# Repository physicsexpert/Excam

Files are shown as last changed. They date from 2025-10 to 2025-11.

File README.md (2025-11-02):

# Excam是一款基于openmv的多功能小相机
## Excam主控采用stm32h7343（stm32h750），搭载1.8寸180°翻转屏，电池，补光灯，RGB灯，按键，SD卡，支持OV5640、OV2640摄像头，支持引脚拓展，兼容openmv固件（引出SWD接口），可以实现色块识别、人脸识别、边缘检测、模板匹配、特征点检测等功能，可以跑一些简单的神经网络模型。

## B站视频链接：
## 开源资料链接：https://pan.quark.cn/s/5be252dfcba2?pwd=E3c6
# 产品渲染图
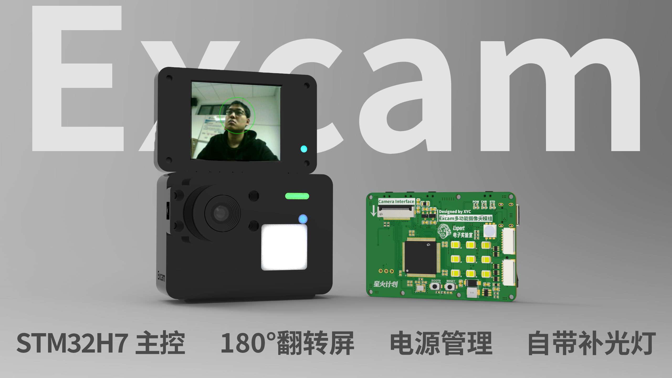
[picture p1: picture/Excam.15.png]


# 产品实物图

## 外观
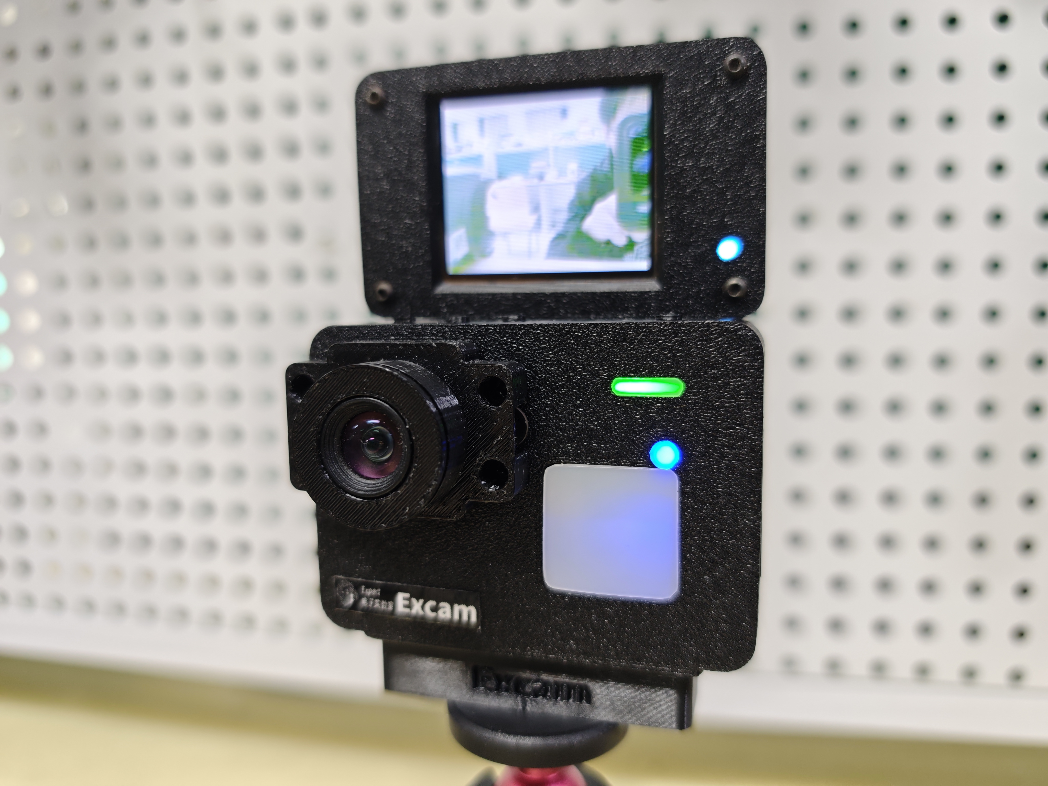
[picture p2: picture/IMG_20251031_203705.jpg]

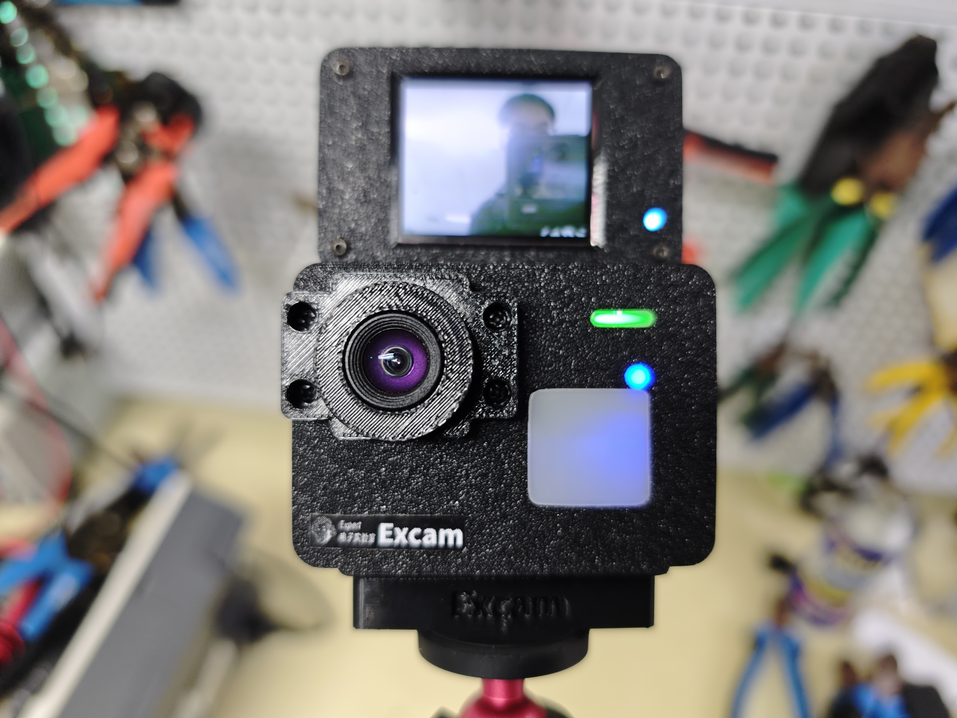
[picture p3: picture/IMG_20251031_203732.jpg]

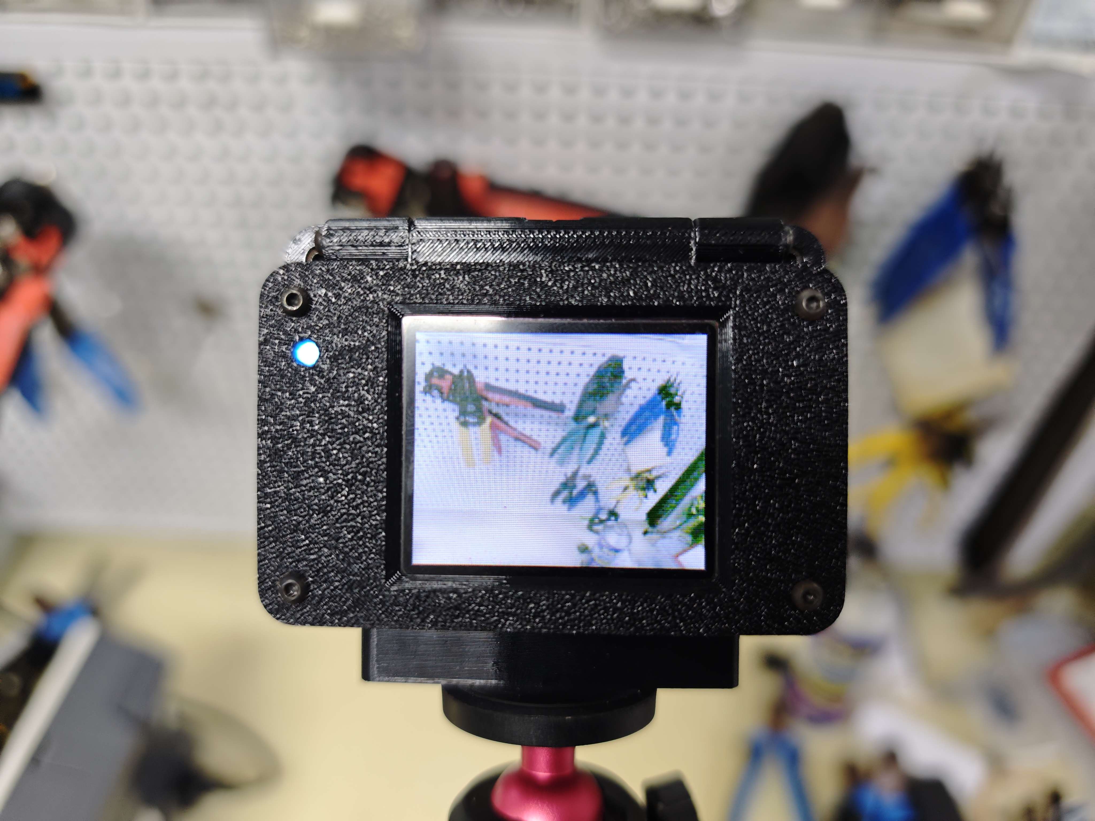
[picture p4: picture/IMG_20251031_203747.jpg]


## 部分功能展示（色块识别、人脸识别、边缘检测、目标检测）
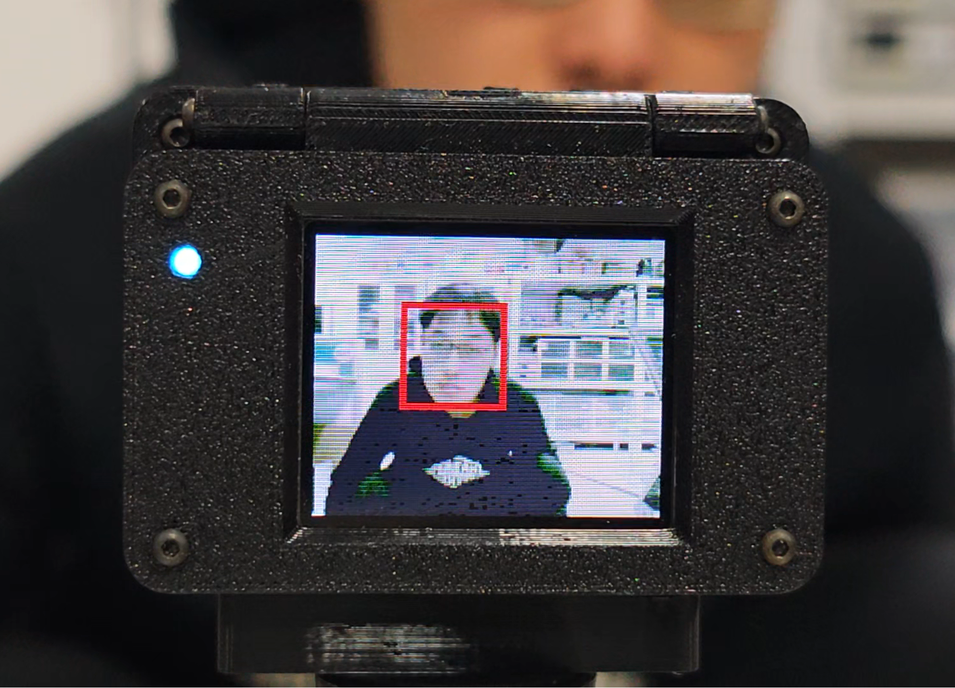
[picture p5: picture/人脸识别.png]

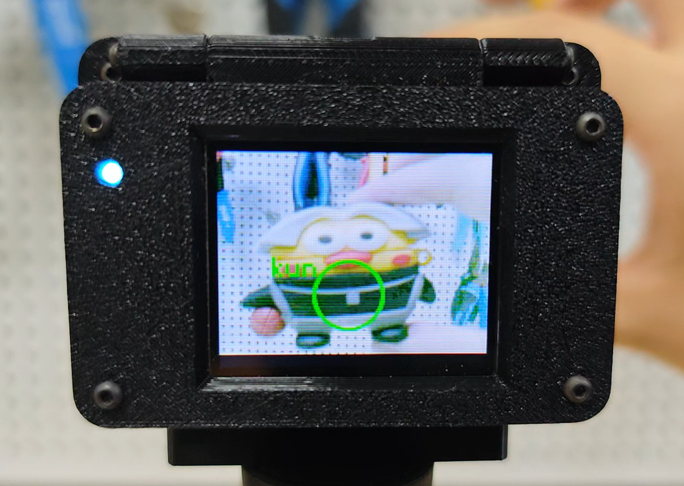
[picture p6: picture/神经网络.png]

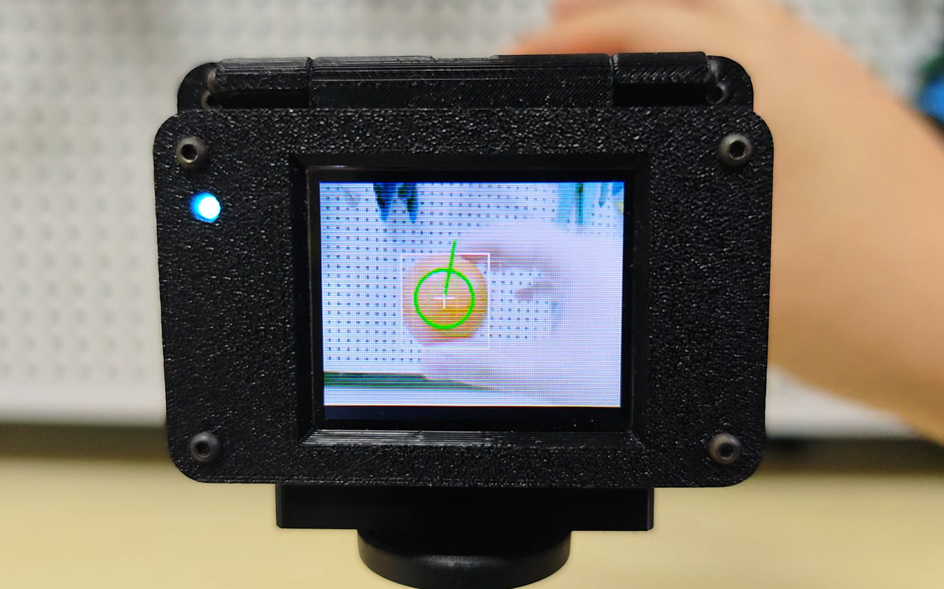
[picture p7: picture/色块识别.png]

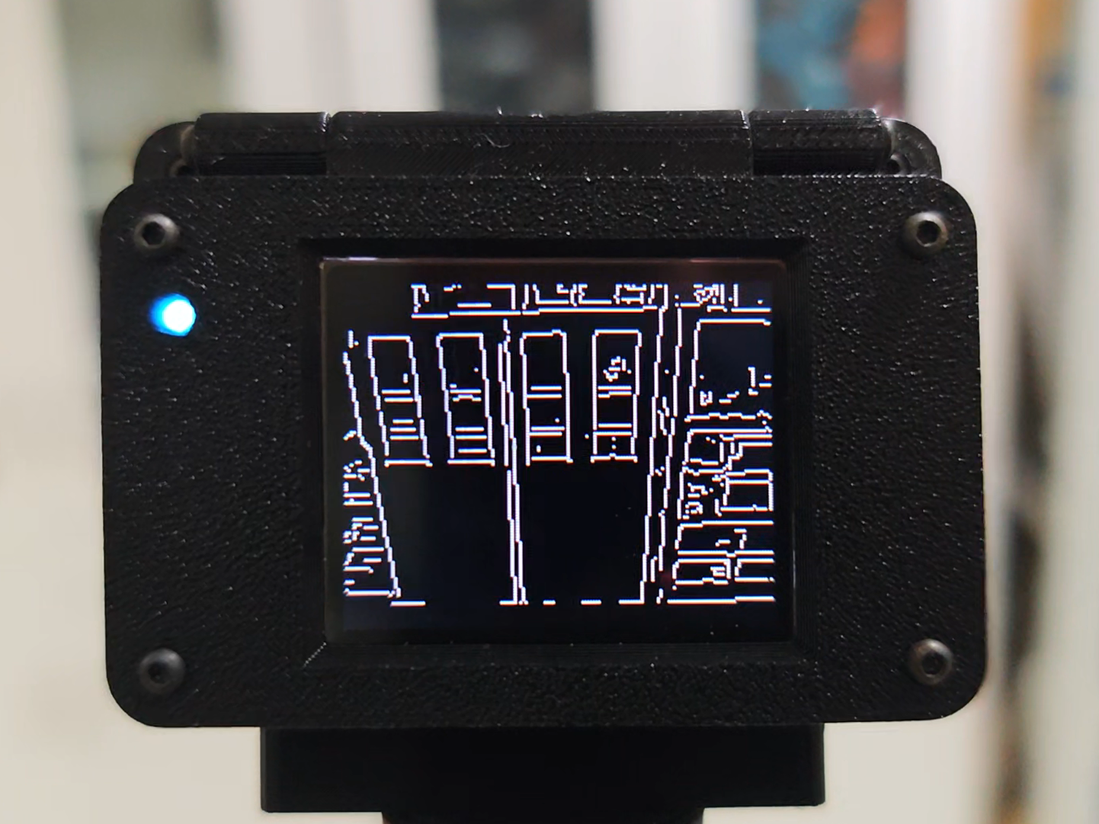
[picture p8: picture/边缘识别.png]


## 所有部件一览
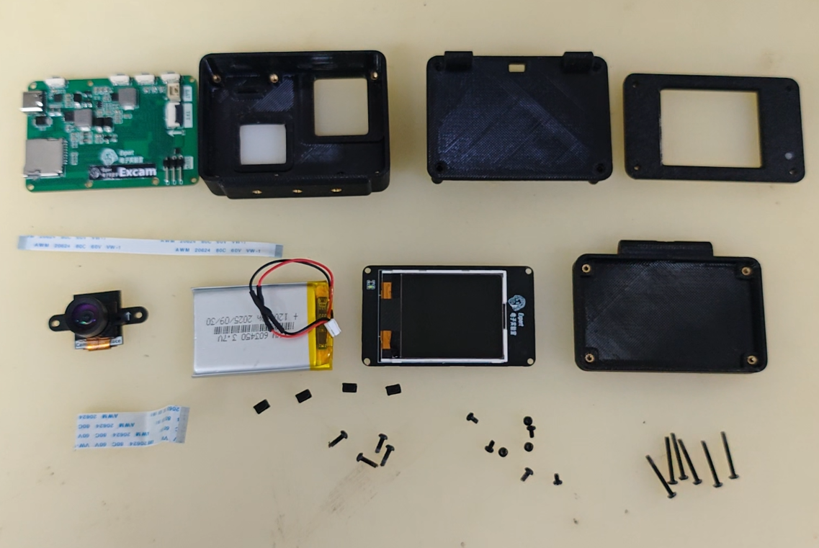
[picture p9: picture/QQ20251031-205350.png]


## 内部结构
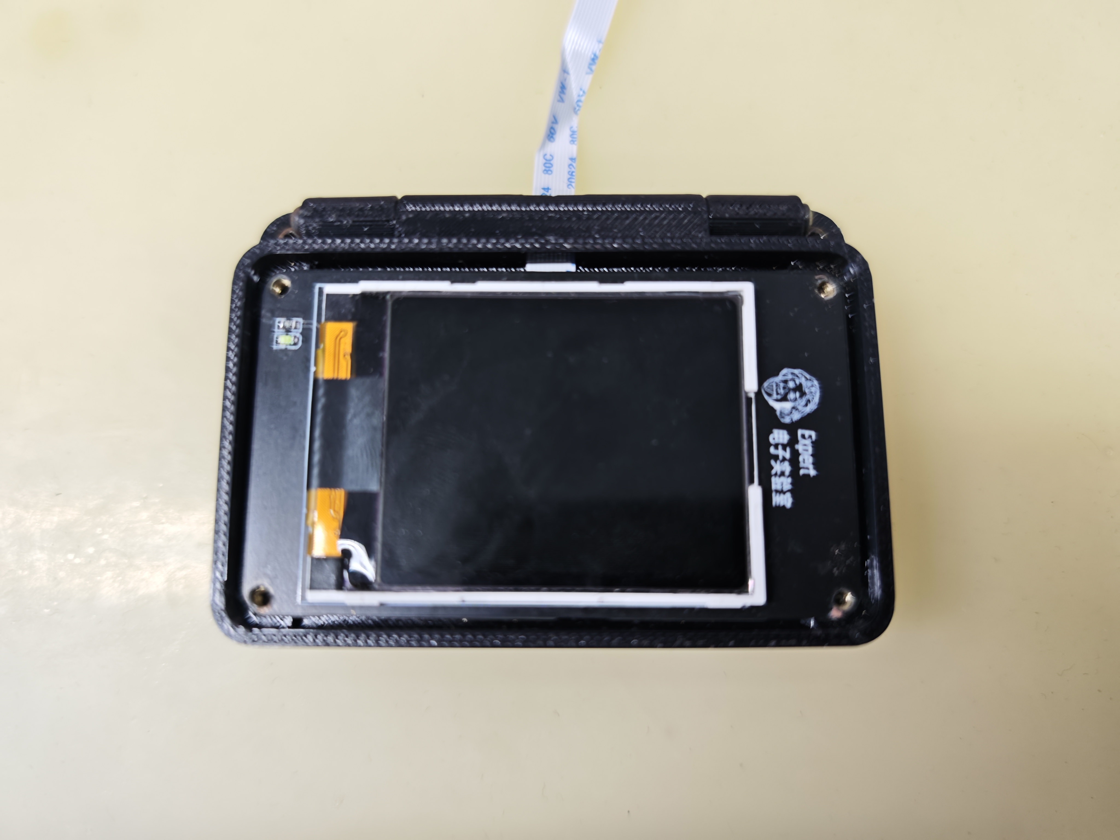
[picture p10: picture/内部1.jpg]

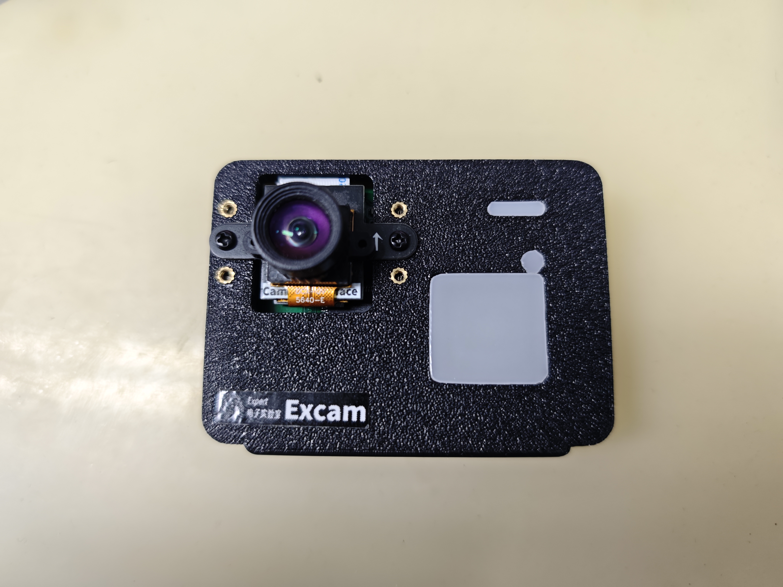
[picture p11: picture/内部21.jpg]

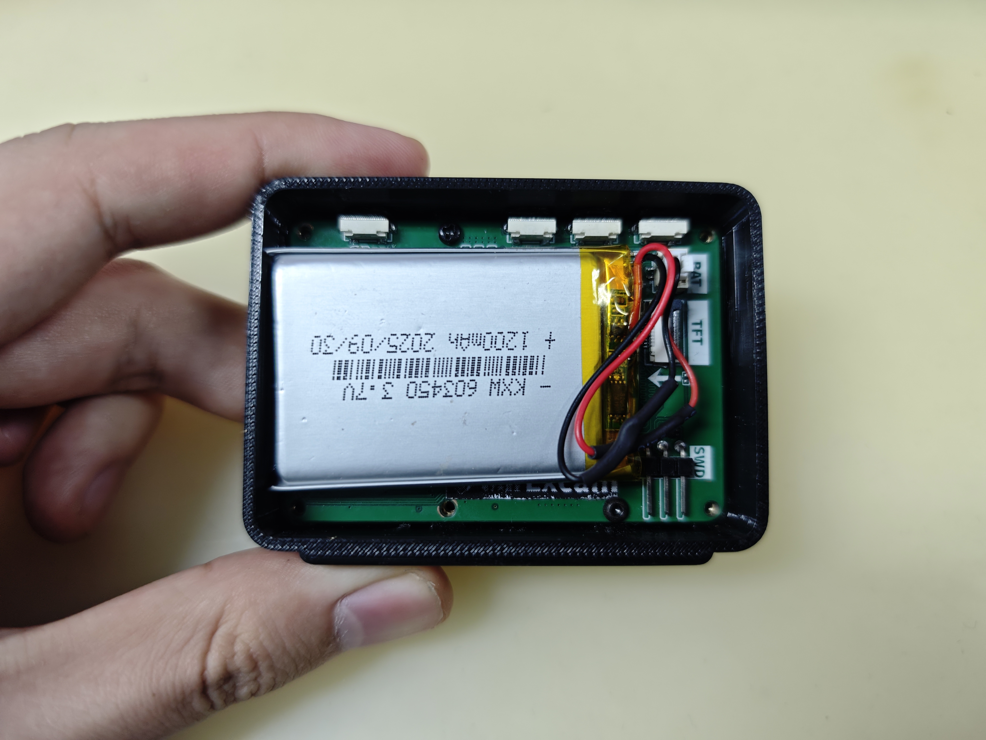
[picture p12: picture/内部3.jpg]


# 硬件说明
## 排针引脚功能（通过侧面SH1.0的接口引出，可以外接杜邦线或者排线）：
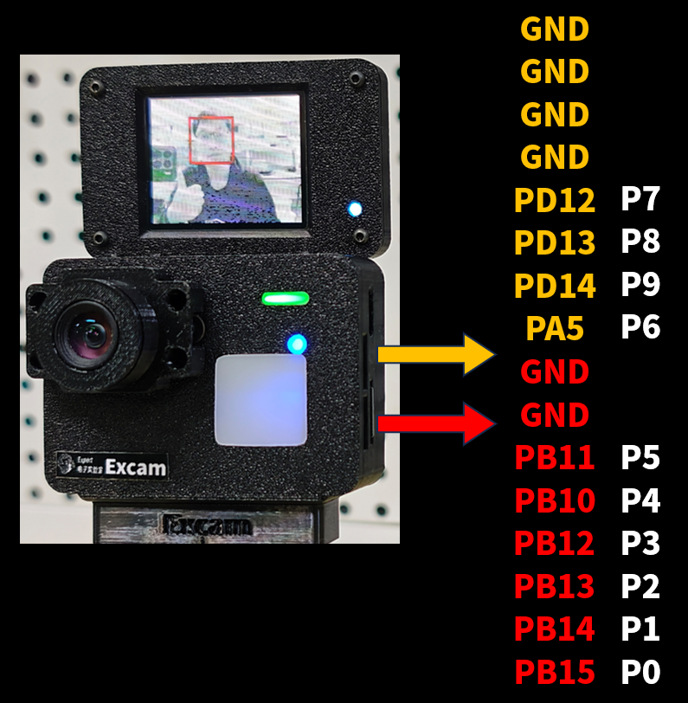
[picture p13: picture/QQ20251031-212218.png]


## 系统框图：
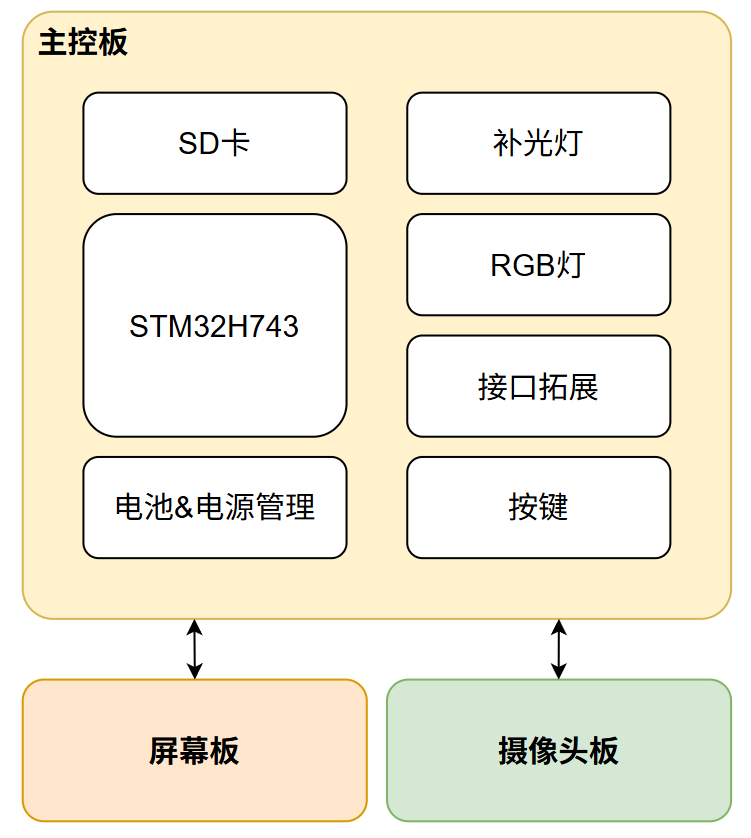
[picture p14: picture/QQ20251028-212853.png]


主控采用主频为480Mhz的stm32h743作为主控芯片，也可以使用stm32h750，外接sd卡和摄像头，openmv固件支持的拓展引脚全部引出，在引脚附近还安排了esd防护器件，保证使用安全

## 系统电源树：
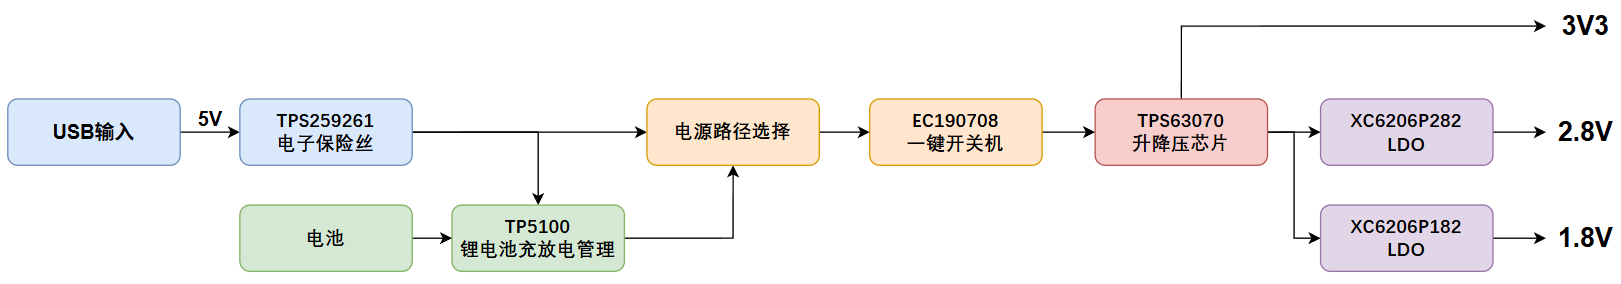
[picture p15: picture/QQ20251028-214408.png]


电源的输入端首先经过TI的TPS259261电子保险丝进行防护，电子保险相较于传统的保险丝方案，支持防过压防反接缓启动等综合防护功能。

锂电池充放电管理采用国产开关型充电ICTP5100，支持最大2A的充电电流，配合TI的TPS63070升降压芯片可以实现稳定的电源输出。

采用一键开关机芯片EC190708，长按三秒开机，之后长按三秒关机，以此类推配合电源路径选择电路，可以实现电源输入的自动切换，即使电源突然掉电也可以保证系统的稳定工作。

对于补光灯的驱动电路，我采用了TI的TPS61165恒流源方案，相比于mos直接驱动的方案，恒流源可以有效维持电流恒定，保证led稳定发光，此外TPS61165还支持pwm亮度调整，我们可以很方便的调整补光灯的亮度。

## PCB结构：
项目由三块PCB构成，主控板为四层板，屏幕板、摄像头板为两层板，采用模块化设计，通过fpc软排线连接。
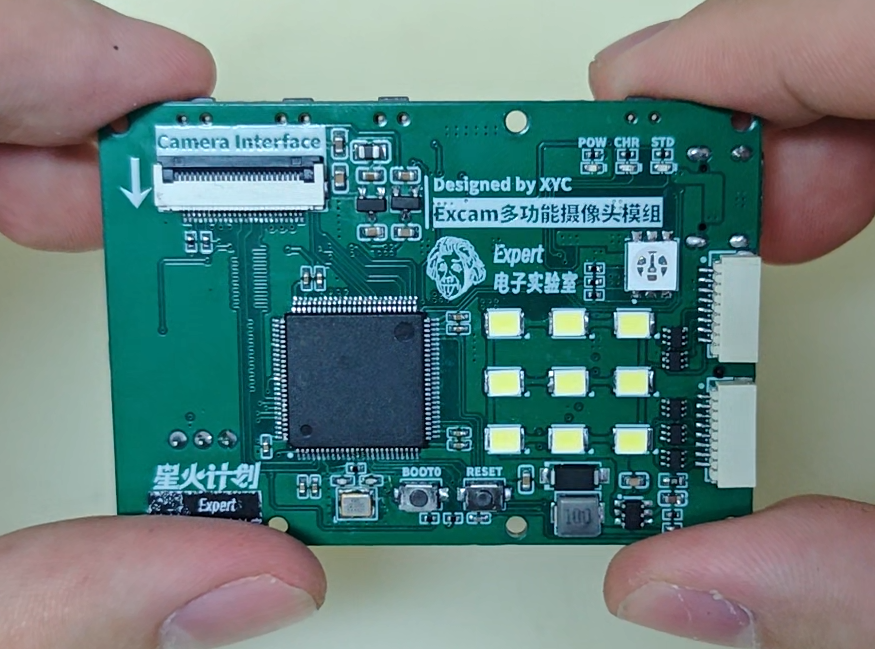
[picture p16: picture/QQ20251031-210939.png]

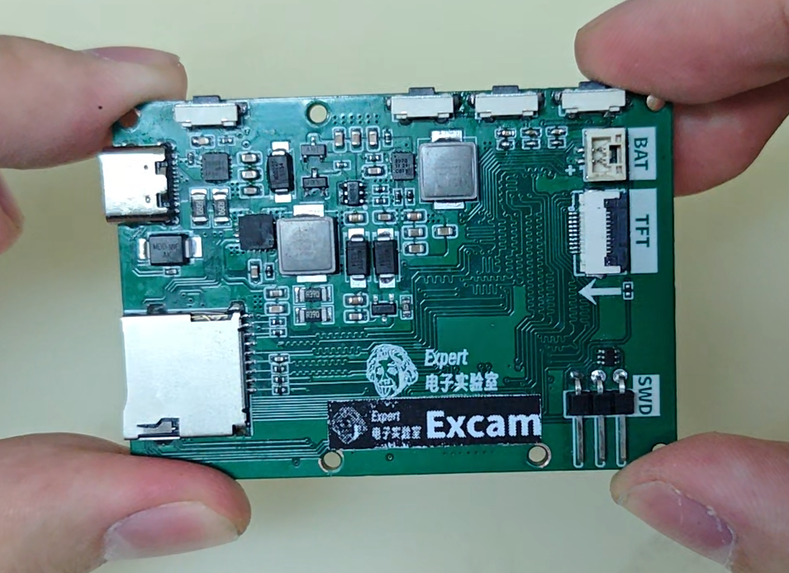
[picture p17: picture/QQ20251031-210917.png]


# 结构说明

调试器外壳采用3D打印制作，总共需要打印七个部分：主控顶壳，主控底壳，屏幕顶壳，屏幕底壳，镜头保护盖，按键（四个），拓展模块，需要用电烙铁压入M2热熔螺母配合M2螺丝进行固定。

# 固件下载
硬件焊接组装好之后，需要烧录openmv的固件：

1.下载STM32CubeProgrammer，下载地址：https://www.st.com/en/development-tools/stm32cubeprog.html

2.使用数据线连接Excam和电脑，按住boot键上电，打开设备调试器可以看到一个DFU设备

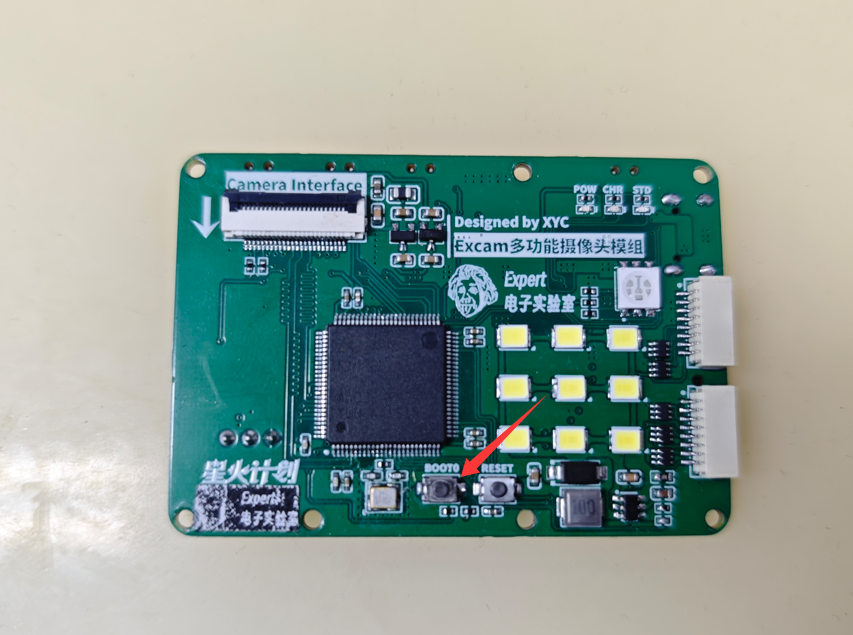
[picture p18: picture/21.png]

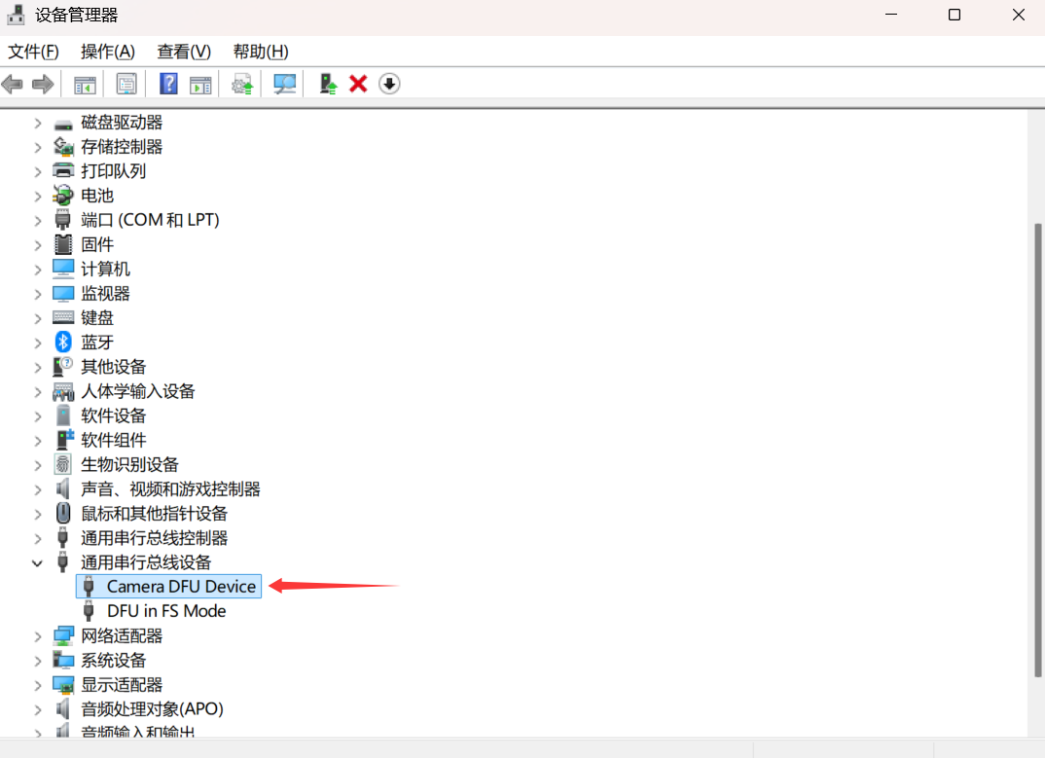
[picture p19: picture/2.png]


3.打开STM32CubeProgrammer，依次点击usb连接，选择openmv固件下载，推荐下载4.6.0版本的固件，也就是我发的压缩包里的固件

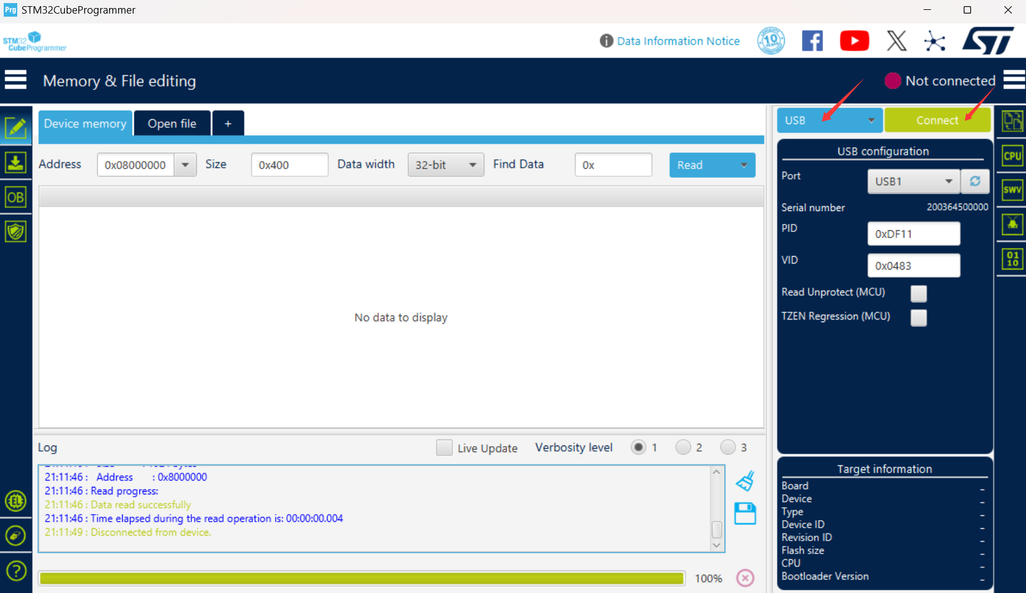
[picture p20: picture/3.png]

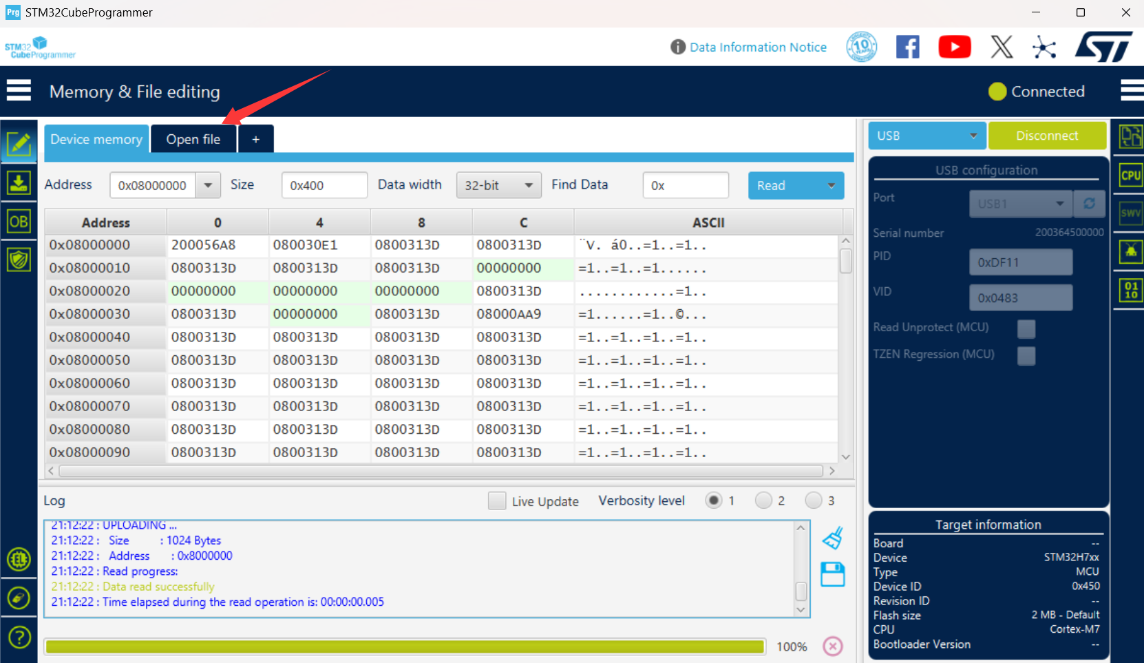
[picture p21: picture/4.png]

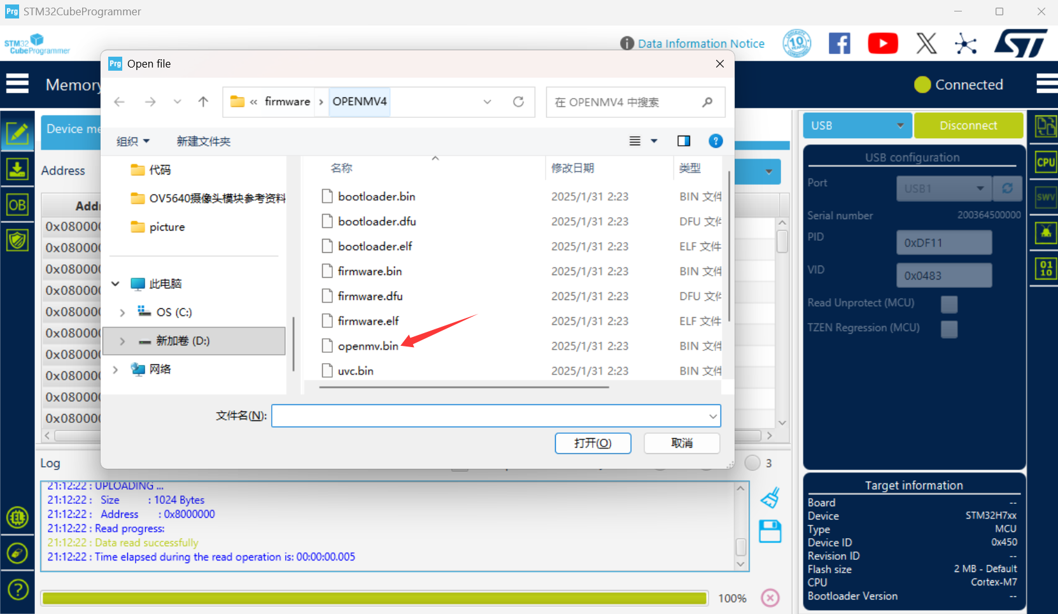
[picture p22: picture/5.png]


4.点击download，看到success之后说明烧录完成

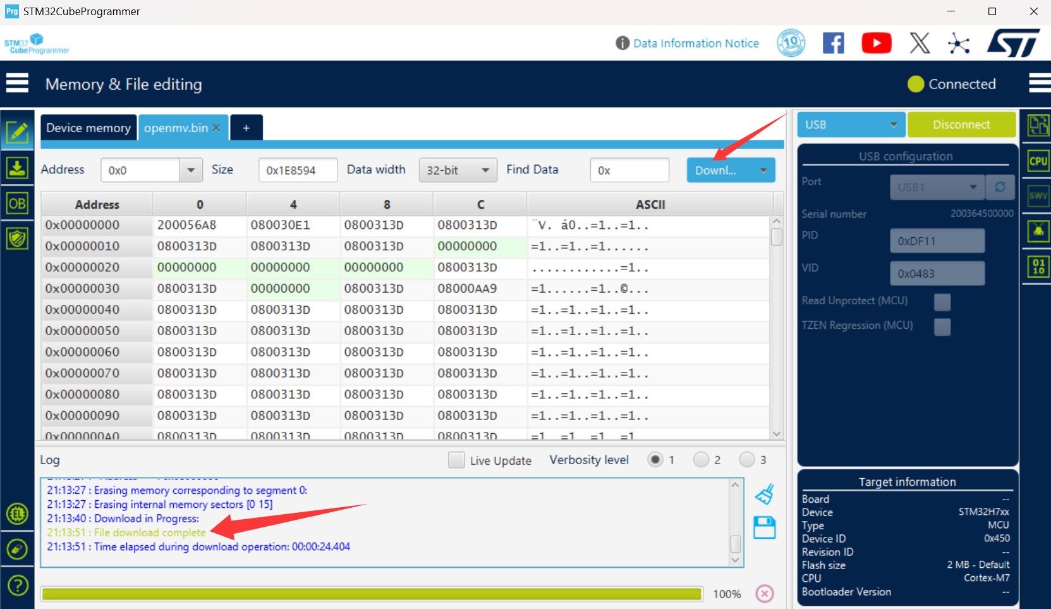
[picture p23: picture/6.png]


5.重新上电连接openmvIDE就可以正常使用了

# 软件使用说明

1.Excam支持的摄像头有OV5640和OV2640，OV5640的帧数较高，OV2640的帧数较低，所以推荐使用OV5640，其他型号的摄像头未测试。

2.摄像头采集的画面反了的话可以使用下面这段代码将摄像头的画面转换成正确的方向
```
sensor.set_hmirror(True)
sensor.set_vflip(True)
```

屏幕的方向反了的话可以使用下面这段代码改变屏幕的显示方向
```
img_processed = img.scale(x_scale=1, y_scale=1, hint=image.ROTATE_90)
lcd.write(img)
```
3.使用Excam运行神经网络模型时，模型训练网站直接生产的代码是不能直接运行的，需要将第21行的
```
net = ml.Model("trained.tflite", load_to_fb=uos.stat('trained.tflite')[6] > (gc.mem_free() - (64*1024)))
```
改成
```
net = ml.Model("/sdcard/trained.tflite", load_to_fb=True)
```
同时需要将下载的ei_object_detection.py、labels.txt和trained.tflite这三个文件放到Excam的SD卡中，IDE中运行i_object_detection.py

4.在你的项目中如果需要屏幕显示的话，可以加入下面这段代码
```
import display
lcd = display.SPIDisplay()
lcd.write(img)
```
5.如果需要使用补光灯的话可以使用下面这段代码
```
import time
from pyb import Pin, Timer
light = Timer(2, freq=50000).channel(1, Timer.PWM, pin=Pin("P6"))
light.pulse_width_percent(50)  # adjust light 0~100
```
6.固件版本需要和OpenMVIDE的软件版本匹配，不匹配的话可能会报错，不确定的话就装4.6.0这个固件版本
# 参考资料
OpenMV：https://github.com/openmv

CloseMV:https://oshwhub.com/bigbirdzzz/closemv4

补光灯方案：https://oshwhub.com/xu_duoduo/heng-liu-yuan-3-3led-bu-guang-deng

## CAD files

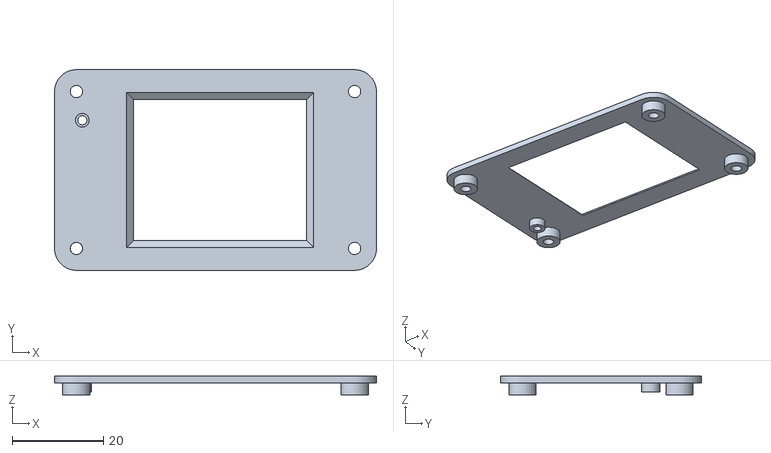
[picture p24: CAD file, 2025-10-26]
model/3D打印（需要根据实际使用的摄像头更改摄像头保护盖的模型）/屏幕上盖.STL
70.6 x 44.0 x 4.10

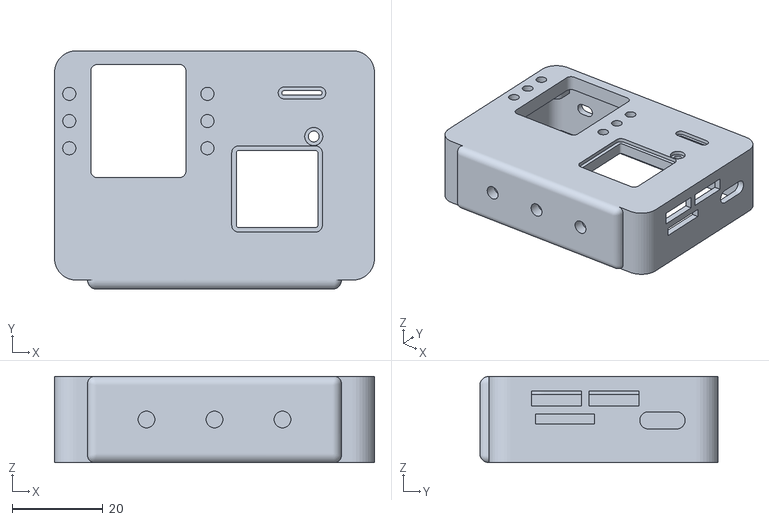
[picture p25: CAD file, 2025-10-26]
model/3D打印（需要根据实际使用的摄像头更改摄像头保护盖的模型）/Excam上壳.STL
70.6 x 52.6 x 19.0

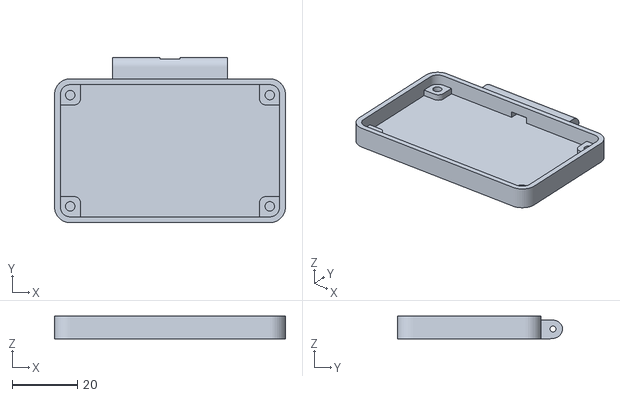
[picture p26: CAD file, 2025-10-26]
model/3D打印（需要根据实际使用的摄像头更改摄像头保护盖的模型）/屏幕下盖.STL
70.6 x 50.6 x 6.90

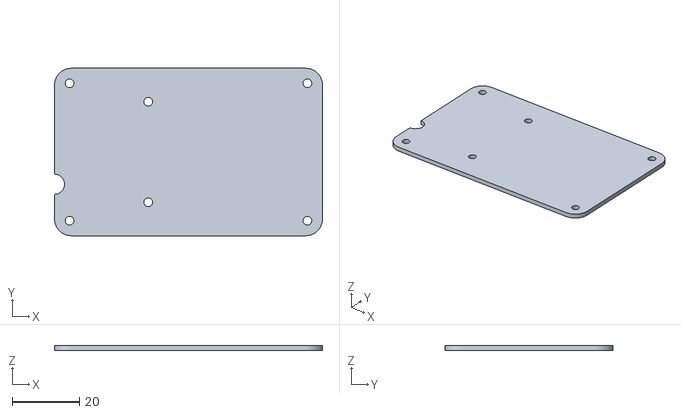
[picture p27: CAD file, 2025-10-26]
model/3D打印（需要根据实际使用的摄像头更改摄像头保护盖的模型）/工程机上壳.STL
80.0 x 50.0 x 1.50

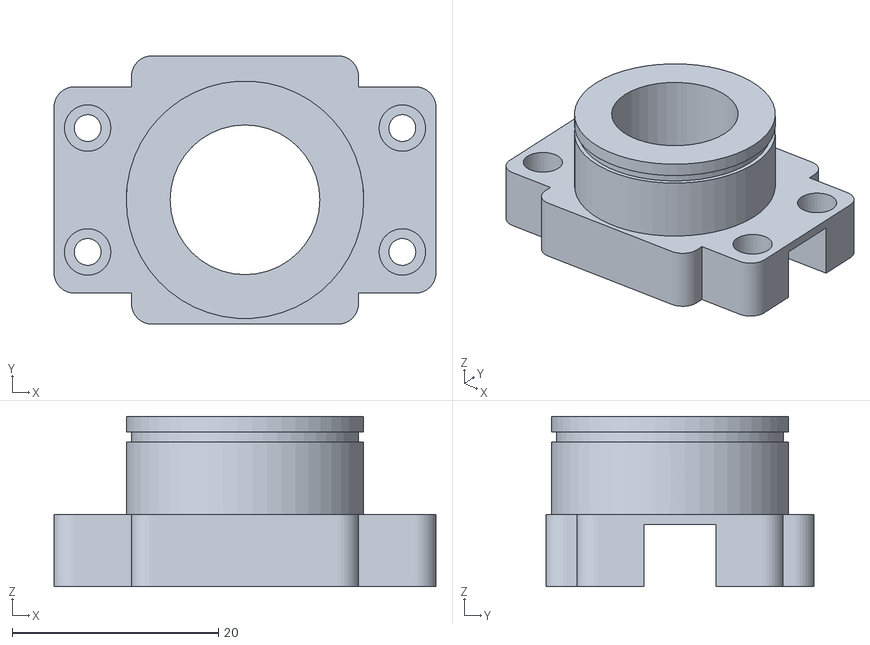
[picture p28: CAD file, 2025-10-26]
model/3D打印（需要根据实际使用的摄像头更改摄像头保护盖的模型）/镜头盖.STL
37.0 x 26.0 x 16.5

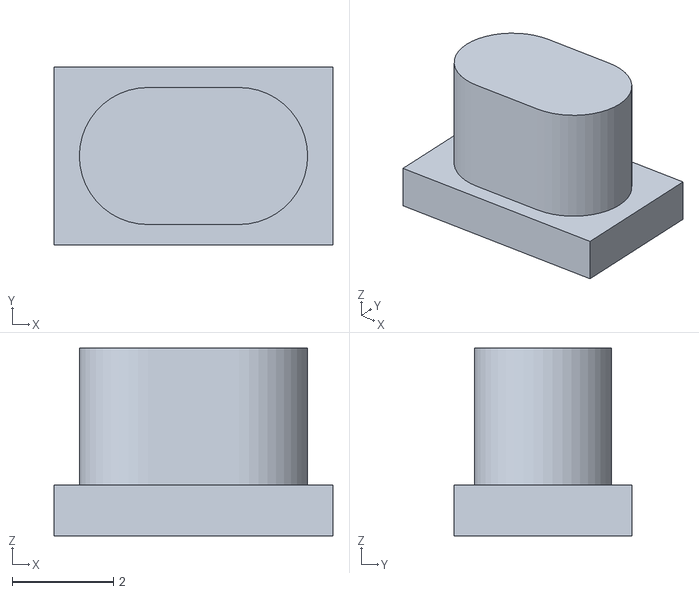
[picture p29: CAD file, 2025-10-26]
model/3D打印（需要根据实际使用的摄像头更改摄像头保护盖的模型）/按键.STL
5.50 x 3.50 x 3.70

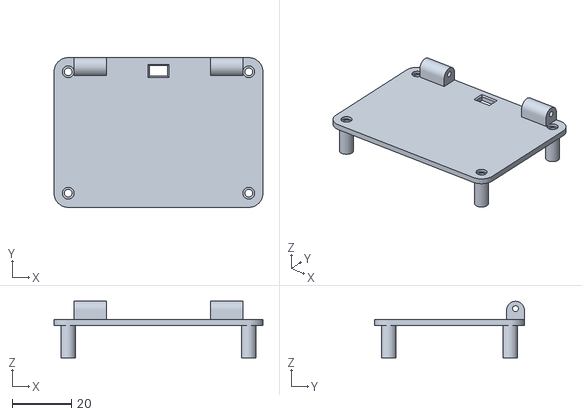
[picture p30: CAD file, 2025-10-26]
model/3D打印（需要根据实际使用的摄像头更改摄像头保护盖的模型）/Excam下壳.STL
70.6 x 50.6 x 19.1

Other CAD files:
model/3D打印（需要根据实际使用的摄像头更改摄像头保护盖的模型）/工程机底壳.3mf
model/3D打印（需要根据实际使用的摄像头更改摄像头保护盖的模型）/工程机底壳.STL

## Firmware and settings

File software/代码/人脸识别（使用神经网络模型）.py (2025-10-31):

# This work is licensed under the MIT license.
# Copyright (c) 2013-2024 OpenMV LLC. All rights reserved.
# https://github.com/openmv/openmv/blob/master/LICENSE
#
# TensorFlow Lite Object Detection Example
#
# This examples uses the builtin FOMO model to detect faces.

import sensor
import time
import ml
from ml.utils import NMS
import math
import image
import display
lcd = display.SPIDisplay()
ROTATION_HINT = image.ROTATE_180  # LCD显示的旋转（按需调整）
SCALE_X, SCALE_Y =1, 1

sensor.reset()  # Reset and initialize the sensor.
sensor.set_pixformat(sensor.RGB565)  # Set pixel format to RGB565 (or GRAYSCALE)
sensor.set_framesize(sensor.QCIF)  # Set frame size to QVGA (320x240)
# sensor.set_windowing((240, 240))  # Set 240x240 window.
sensor.skip_frames(time=2000)  # Let the camera adjust.

min_confidence = 0.6
threshold_list = [(math.ceil(min_confidence * 255), 255)]

# Load built-in FOMO face detection model
model = ml.Model("fomo_face_detection")
print(model)

# Alternatively, models can be loaded from the filesystem storage.
# model = ml.Model('<object_detection_modelwork>.tflite', load_to_fb=True)
# labels = [line.rstrip('\n') for line in open("labels.txt")]

colors = [  # Add more colors if you are detecting more than 7 types of classes at once.
    (255, 0, 0),
    (0, 255, 0),
    (255, 255, 0),
    (0, 0, 255),
    (255, 0, 255),
    (0, 255, 255),
    (255, 255, 255),
]


# FOMO outputs an image per class where each pixel in the image is the centroid of the trained
# object. So, we will get those output images and then run find_blobs() on them to extract the
# centroids. We will also run get_stats() on the detected blobs to determine their score.
# The Non-Max-Supression (NMS) object then filters out overlapping detections and maps their
# position in the output image back to the original input image. The function then returns a
# list per class which each contain a list of (rect, score) tuples representing the detected
# objects.
def fomo_post_process(model, inputs, outputs):
    n, oh, ow, oc = model.output_shape[0]
    nms = NMS(ow, oh, inputs[0].roi)
    for i in range(oc):
        img = image.Image(outputs[0][0, :, :, i] * 255)
        blobs = img.find_blobs(
            threshold_list, x_stride=1, area_threshold=1, pixels_threshold=1
        )
        for b in blobs:
            rect = b.rect()
            x, y, w, h = rect
            score = (
                img.get_statistics(thresholds=threshold_list, roi=rect).l_mean() / 255.0
            )
            nms.add_bounding_box(x, y, x + w, y + h, score, i)
    return nms.get_bounding_boxes()


clock = time.clock()
while True:
    clock.tick()

    img = sensor.snapshot()

    for i, detection_list in enumerate(model.predict([img], callback=fomo_post_process)):
        if i == 0:
            continue  # background class
        if len(detection_list) == 0:
            continue  # no detections for this class?

        print("********** %s **********" % model.labels[i])
        for (x, y, w, h), score in detection_list:
            center_x = math.floor(x + (w / 2))
            center_y = math.floor(y + (h / 2))
            print(f"x {center_x}\ty {center_y}\tscore {score}")
            img.draw_circle((center_x, center_y, 15), color=0xF800,thickness=3)
    img_processed = img.scale(x_scale=SCALE_X, y_scale=SCALE_Y, hint=image.ROTATE_270)
    lcd.write(img)  # Take a picture and display the image.
    img_processed = img.scale(x_scale=SCALE_X, y_scale=SCALE_Y, hint=image.ROTATE_270)
    print(clock.fps(), "fps", end="\n")

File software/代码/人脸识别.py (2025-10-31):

# This work is licensed under the MIT license.
# Copyright (c) 2013-2023 OpenMV LLC. All rights reserved.
# https://github.com/openmv/openmv/blob/master/LICENSE
#
# Face Detection Example
#
# This example shows off the built-in face detection feature of the OpenMV Cam.
#
# Face detection works by using the Haar Cascade feature detector on an image. A
# Haar Cascade is a series of simple area contrasts checks. For the built-in
# frontalface detector there are 25 stages of checks with each stage having
# hundreds of checks a piece. Haar Cascades run fast because later stages are
# only evaluated if previous stages pass. Additionally, your OpenMV Cam uses
# a data structure called the integral image to quickly execute each area
# contrast check in constant time (the reason for feature detection being
# grayscale only is because of the space requirement for the integral image).

import sensor
import time
import image
import display
import pyb
from pyb import Pin, Timer
from machine import LED
led = LED("LED_BLUE")
led.on()

lcd = display.SPIDisplay()
ROTATION_HINT = image.ROTATE_180  # LCD显示的旋转（按需调整）
SCALE_X, SCALE_Y =1, 1
# Reset sensor
sensor.reset()

# Sensor settings
sensor.set_contrast(3)
sensor.set_gainceiling(16)
# HQVGA and GRAYSCALE are the best for face tracking.
sensor.set_framesize(sensor.QCIF)
sensor.set_pixformat(sensor.RGB565)

# Load Haar Cascade
# By default this will use all stages, lower satges is faster but less accurate.
face_cascade = image.HaarCascade("frontalface", stages=20)
print(face_cascade)

# FPS clock
clock = time.clock()

while True:
    clock.tick()

    # Capture snapshot
    img = sensor.snapshot()
    img_processed = img.scale(x_scale=SCALE_X, y_scale=SCALE_Y, hint=image.ROTATE_180)
    # Find objects.
    # Note: Lower scale factor scales-down the image more and detects smaller objects.
    # Higher threshold results in a higher detection rate, with more false positives.
    objects = img.find_features(face_cascade, threshold=0.5, scale_factor=1.25)

    # Draw objects
    for r in objects:
        img.draw_rectangle(r,color=0xF800,thickness=3)


    # Print FPS.
    # Note: Actual FPS is higher, streaming the FB makes it slower.
    print(clock.fps())
    img_processed = img.scale(x_scale=SCALE_X, y_scale=SCALE_Y, hint=image.ROTATE_270)
    lcd.write(img)  # Take a picture and display the image.
